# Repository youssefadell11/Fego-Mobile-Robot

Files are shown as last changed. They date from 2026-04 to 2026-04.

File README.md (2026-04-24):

# Fego Mobile Robot
This documentation provides a comprehensive overview of the design, assembly, and testing of the Fego mobile robot, a differential drive platform equipped with LiDAR and camera sensors. The project encompasses 3D CAD modeling, hardware integration, software visualization, and real-world performance demonstrations.

## 1. 3D CAD Design (Fusion 360)
The chassis and component placements were initially modeled in Autodesk Fusion 360 to ensure optimal weight distribution and sensor mounting.

<p align="center">
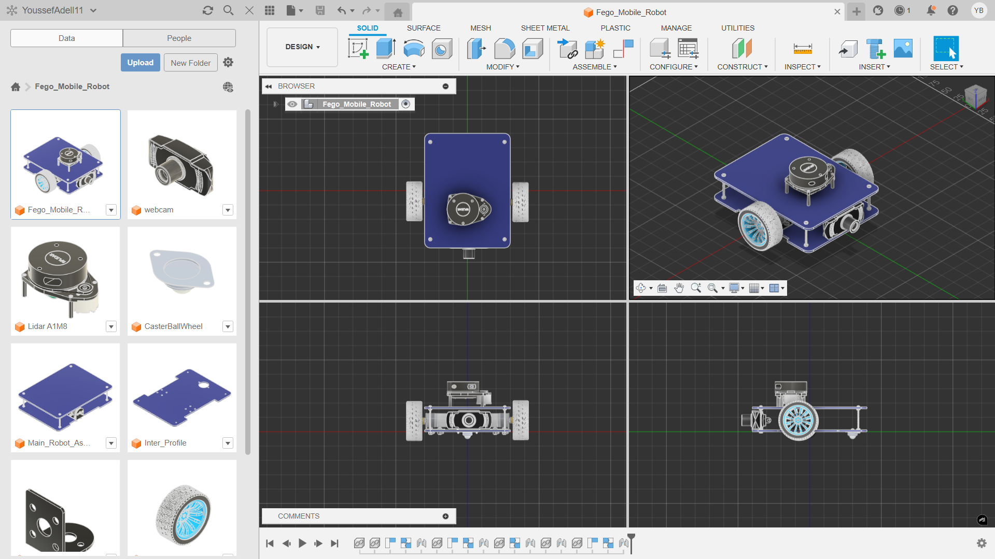
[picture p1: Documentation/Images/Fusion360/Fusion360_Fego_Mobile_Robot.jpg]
Fusion 360 Overall Model
  
</p>

<p align="center">
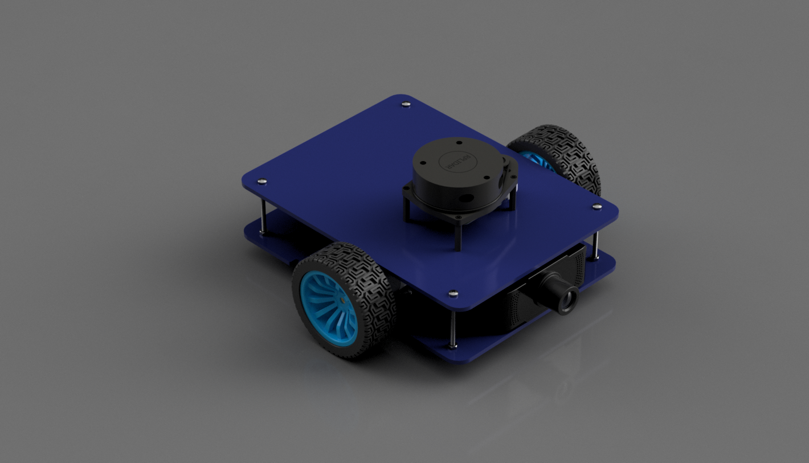
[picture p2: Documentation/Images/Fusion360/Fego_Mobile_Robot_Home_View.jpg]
Home View
  
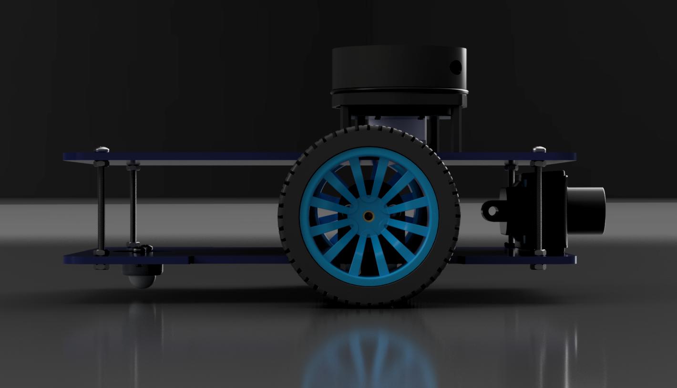
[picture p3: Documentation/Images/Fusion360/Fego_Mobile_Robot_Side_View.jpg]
Side View
  
</p>

---

## 2. Hardware Assembly & Real Robot
The physical build incorporates DC motors, an L298N motor driver, LiDAR, and a camera module. 

### Electronics & Wiring
<p align="center">
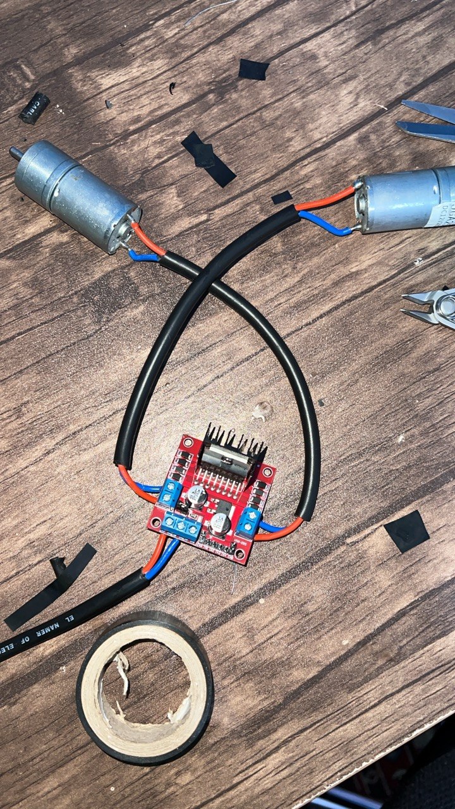
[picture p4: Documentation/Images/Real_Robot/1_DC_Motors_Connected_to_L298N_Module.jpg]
DC Motors Wiring
  
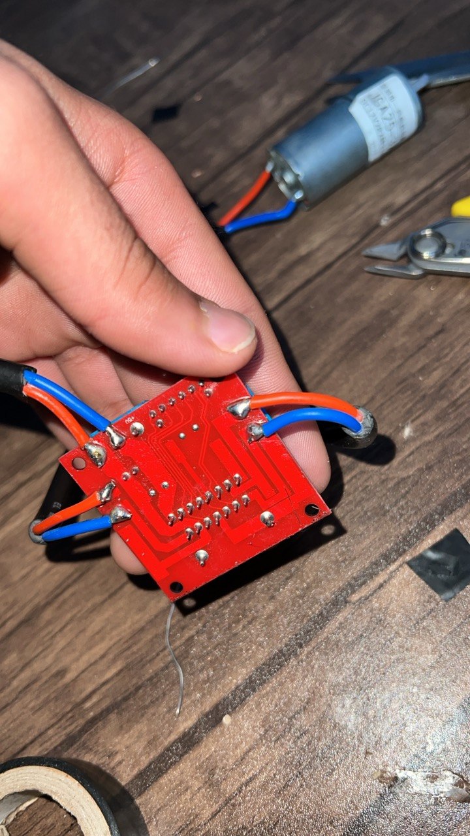
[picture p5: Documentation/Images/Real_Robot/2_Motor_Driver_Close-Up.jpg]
Motor Driver
  
</p>

### Chassis & Assembly Layout
<p align="center">
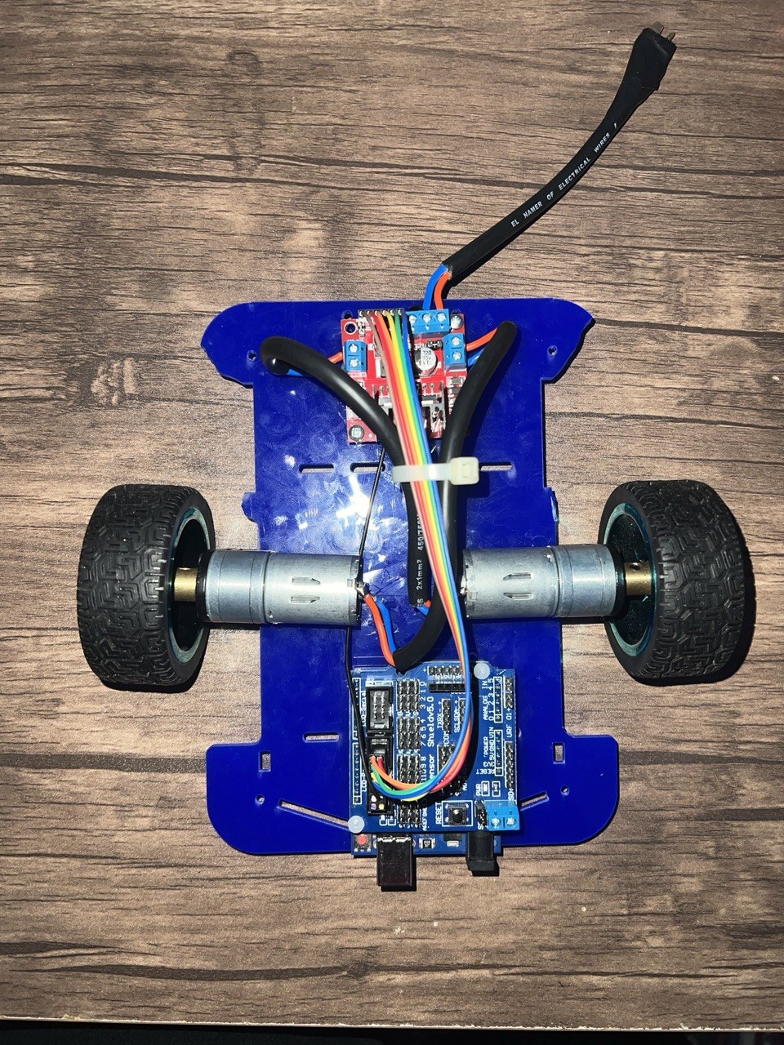
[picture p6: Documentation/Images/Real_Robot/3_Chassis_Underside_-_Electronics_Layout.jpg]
Underside Electronics
  
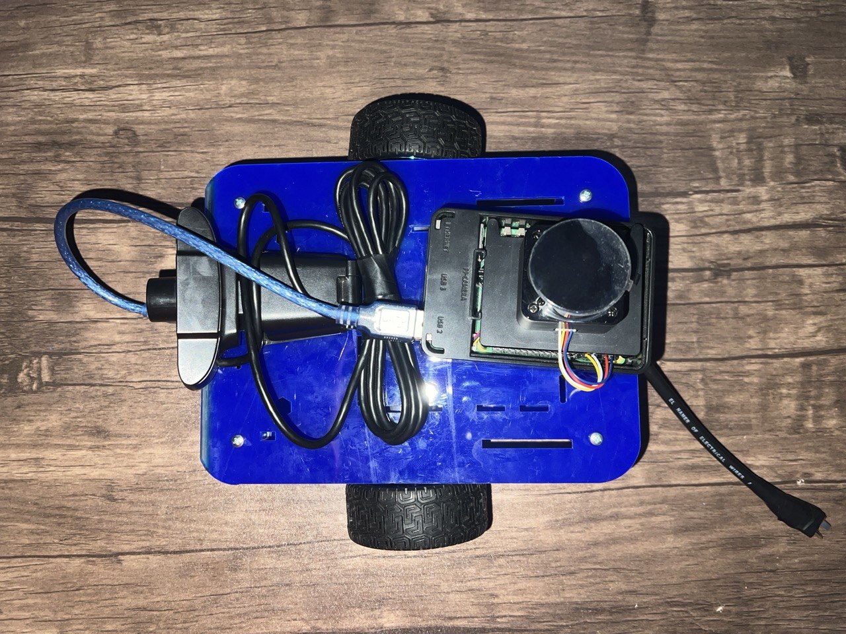
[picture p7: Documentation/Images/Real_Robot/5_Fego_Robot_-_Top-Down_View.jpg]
Top-Down View
  
</p>

### Final Assembled Platform
<p align="center">
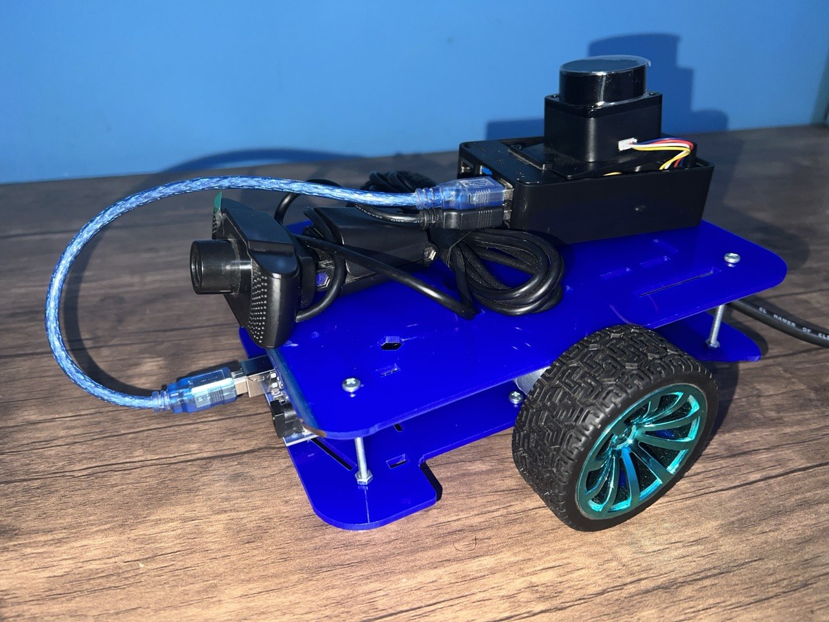
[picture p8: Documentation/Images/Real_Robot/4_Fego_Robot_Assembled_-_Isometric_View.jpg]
Fully Assembled Fego Robot
  
</p>

---

## 3. Software & Visualization
The robot's URDF, sensor data, and odometry are visualized in real-time using RViz.

<p align="center">
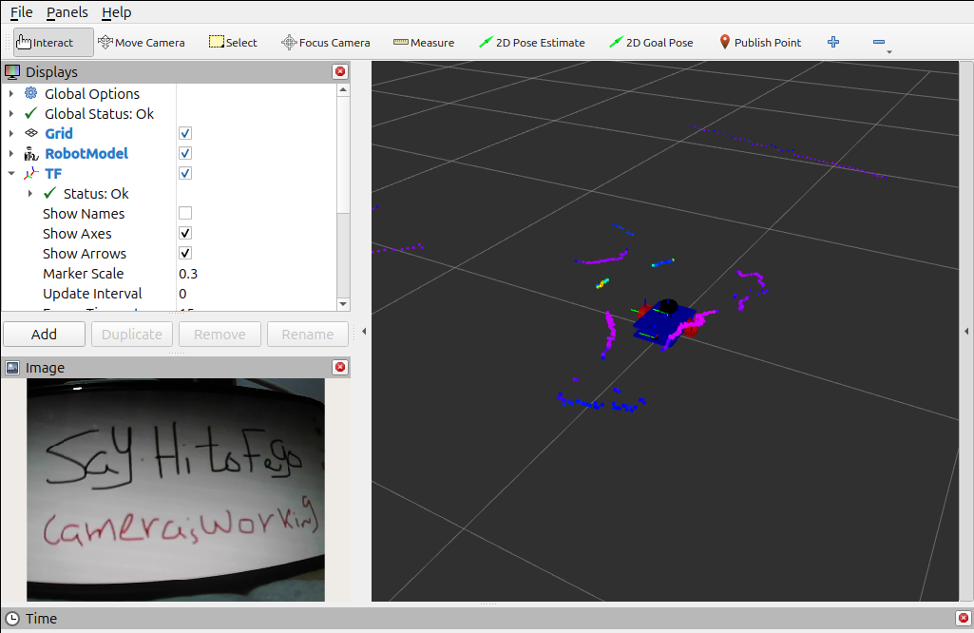
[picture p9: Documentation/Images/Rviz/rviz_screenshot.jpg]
RViz Visualization
  
</p>

---

## 4. Real-World Testing
Watch the Fego mobile base navigating and demonstrating its differential drive system and `ros2_control` integration.

<p align="center">
  <em>Please hit the image to see the YouTube video!</em><br>
</p>
<p align="center">
  <a href="https://youtu.be/x8awXbyMQPw">
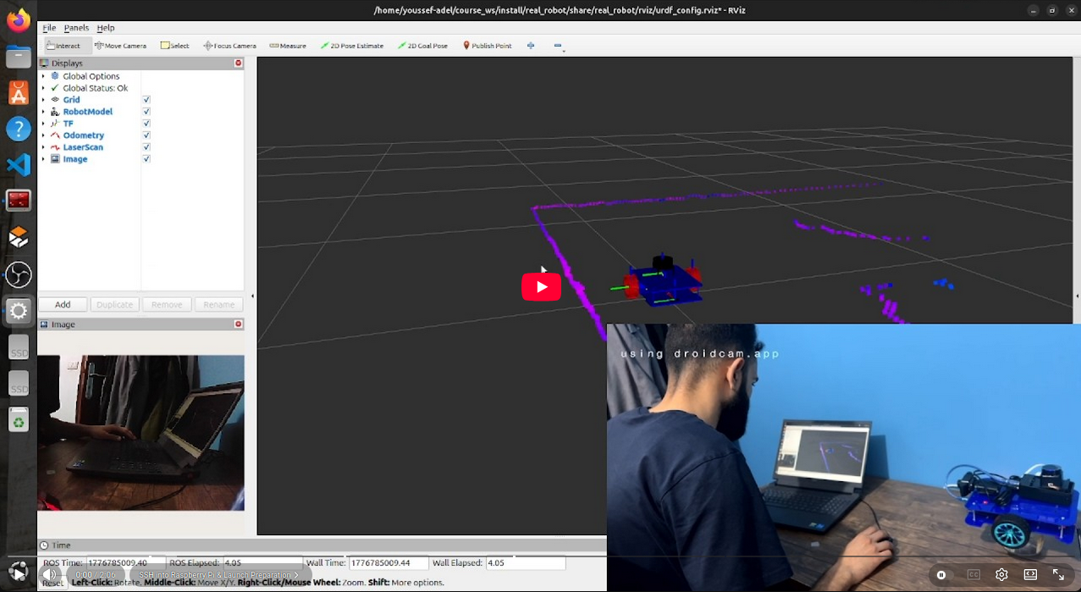
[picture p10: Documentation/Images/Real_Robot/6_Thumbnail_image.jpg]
Click to watch the Fego Robot video
    
  </a>
</p>

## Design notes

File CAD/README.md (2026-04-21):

# Fego Mobile Robot CAD

Welcome to the open-source CAD folder for the **Fego Mobile Robot**! This is a 2-Wheel Drive (2WD) differential mobile robot designed from the bottom-up using **`Fusion 360`**. 

This folder contains all the mechanical CAD files, manufacturing 2D profiles, and 3D meshes required to build the physical robot or simulate it in ROS 2 (RViz/Gazebo).
<p align="center">
Fusion360 Fego Mobile Robot
</p>

## 🗂️ Folder Structure

The CAD files in this folder are organized to help you find exactly what you need, whether you want to 3D print the whole robot, cut the chassis, or just borrow a sensor model for your own project.

### **`1_Full_Assembly/`**
Contains the complete, assembled robot model.
* `.step` - Universal 3D CAD file (Open in SolidWorks, Inventor, Onshape, etc.)
* `.f3d` - Native Fusion 360 archive with the complete design timeline and linked components.

### **`2_Components/`**
Individual `.step` files for standard third-party hardware and custom parts. You can easily drag and drop these into your own custom robot designs!
* Inter Profile
* Outer Profile
* Bracket 25mm
* RPLidar A1M8
* JGA25-370 TT Geared Motors
* 65mm Robot Wheels
* Caster Ball Wheel
* Webcam Module

### **`3_Manufacture_Files/`**
2D profiles and files for fabricating the custom parts.
* `.dxf` - Files for laser cutting or CNC routing the acrylic top and bottom plates.
* `.stl` - Files for 3D printing the 25mm Brackets.

### **`4_Meshes/`**
Optimized 3D meshes specifically exported for ROS 2 simulation (RViz/Gazebo).
* `lidar.stl`
* `base_link.stl`
* `camera.stl`
* `caster.stl`
* `wheel.stl`

### **`5_Renders/`**
High-quality, photorealistic images of the final assembly for reference and documentation.

---

## 🛠️ Main Components List

To build the electrical and sensor stack of this robot, the following major components are used:

* **Controller:** Arduino Mega (or Uno) & H-Bridge Motor Driver
* **Actuators:** 2x JGA25-370 TT Geared DC Motors with Encoders
* **Wheels:** 2x 65mm Rubber Tires with Plastic Rims, 1x Front Caster Ball Wheel
* **Vision / LiDAR:** RPLIDAR A1M8 & Forward-facing USB Webcam
* **Chassis:** 2x Custom Acrylic Plates (Top and Bottom)

---

## 🔩 Hardware & Fasteners Bill of Materials (BOM)

Below is the required hardware matrix for assembling the mechanical chassis and mounting the electronics.

| Subsystem / Assembly | Screws Required | Nuts Required | Spacers / Extras |
| :--- | :--- | :--- | :--- |
| **Main Chassis (Plates 1 & 2)** | 4x M3x50 | 12x M3 | - |
| **Motor Brackets** | 8x M4 | 8x M4 | - |
| **TT Motors** | 4x M3 | - | - |
| **Caster Wheel** | 2x M3 | 2x M3 | - |
| **Arduino & H-Bridge** | 8x M3 | 8x M3 | 8x M3 Spacers |

---

## 🚀 Getting Started

**To build the physical robot:**
1. Laser cut the top and bottom plates using the `.dxf` files in `3_Manufacture_Files/`.
2. 3D print the 25mm brackets.
3. Gather the components listed in the BOM.
4. Use the `1_Full_Assembly/` `.step` or `.f3d` file as a visual guide for putting it all together.

**To simulate in ROS 2:**
1. Copy the contents of `4_Meshes/` into the `meshes` folder of your ROS 2 description package.
2. Link them in your URDF/Xacro file. 

## 🇪🇬 Local Sourcing (Egyptian Market)
If you are building this robot in Egypt, you can easily source the main mechanical components from local electronics suppliers:

* **[Metal Caster Wheel](https://makerselectronics.com/product/metal-caster-wheel-for-robot/)** 
  * *Makers Electronics*
* **[Main Chassis / 2WD Platform](https://makerselectronics.com/product/robot-platform-2wd-square-shape/)** 
  * *Makers Electronics* (Note: This is a great alternative if you don't want to laser cut the custom acrylic plates).
* **[65mm Wheel & TT Motor Kit](https://electra.store/products/robot-wheel-65mm-with-gear-motor)** 
  * *Electra Store* (Includes the 65mm rubber wheels, TT gear motors, and the necessary motor mounting brackets).

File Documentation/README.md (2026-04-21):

# Fego Mobile Robot Documentation
This documentation provides a comprehensive overview of the design, assembly, and testing of the Fego mobile robot, a differential drive platform equipped with LiDAR and camera sensors. The project encompasses 3D CAD modeling, hardware integration, software visualization, and real-world performance demonstrations.

## 1. 3D CAD Design (Fusion 360)
The chassis and component placements were initially modeled in Autodesk Fusion 360 to ensure optimal weight distribution and sensor mounting.

<p align="center">
  Fusion 360 Overall Model
</p>

<p align="center">
  Home View
  Side View
</p>

---

## 2. Hardware Assembly & Real Robot
The physical build incorporates DC motors, an L298N motor driver, LiDAR, and a camera module. 

### Electronics & Wiring
<p align="center">
  DC Motors Wiring
  Motor Driver
</p>

### Chassis & Assembly Layout
<p align="center">
  Underside Electronics
  Top-Down View
</p>

### Final Assembled Platform
<p align="center">
  Fully Assembled Fego Robot
</p>

---

## 3. Software & Visualization
The robot's URDF, sensor data, and odometry are visualized in real-time using RViz.

<p align="center">
  RViz Visualization
</p>

---

## 4. Real-World Testing
Watch the Fego mobile base navigating and demonstrating its differential drive system and `ros2_control` integration.

<p align="center">
  <em>Please hit the image to see the YouTube video!</em><br>
</p>
<p align="center">
  <a href="https://youtu.be/x8awXbyMQPw">
    Click to watch the Fego Robot video
  </a>
</p>

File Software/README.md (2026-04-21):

# Fego Mobile Robot Software

A ROS 2 Jazzy differential-drive robot with Arduino-based motor control, LiDAR, and a USB camera. Three workspaces cover the full stack — from microcontroller firmware to remote visualization.





---

## 📁 Repository Structure

```
Fego/
├── firmware/       # Arduino sketch — low-level PWM motor driver
├── rpi_ws/         # Raspberry Pi workspace — core ROS 2 stack
├── laptop_ws/      # Laptop workspace — visualization & teleoperation
└── README.md       # This file
```
---

## 🖼️ System Visualization

### 💻 RViz2 Visualization

<p align="center">
Fusion360 Fego Mobile Robot
</p>
<p align="center">
Figure 1: Rviz2 showing the Fego Robot URDF, LaserScan data, and Camera feed.
</p>

### 🔄 Topic Network Overview
The system relies on a distributed node network. High-level commands flow from the Laptop to the Pi 5, while sensor data and hardware states flow back. 

<p align="center">
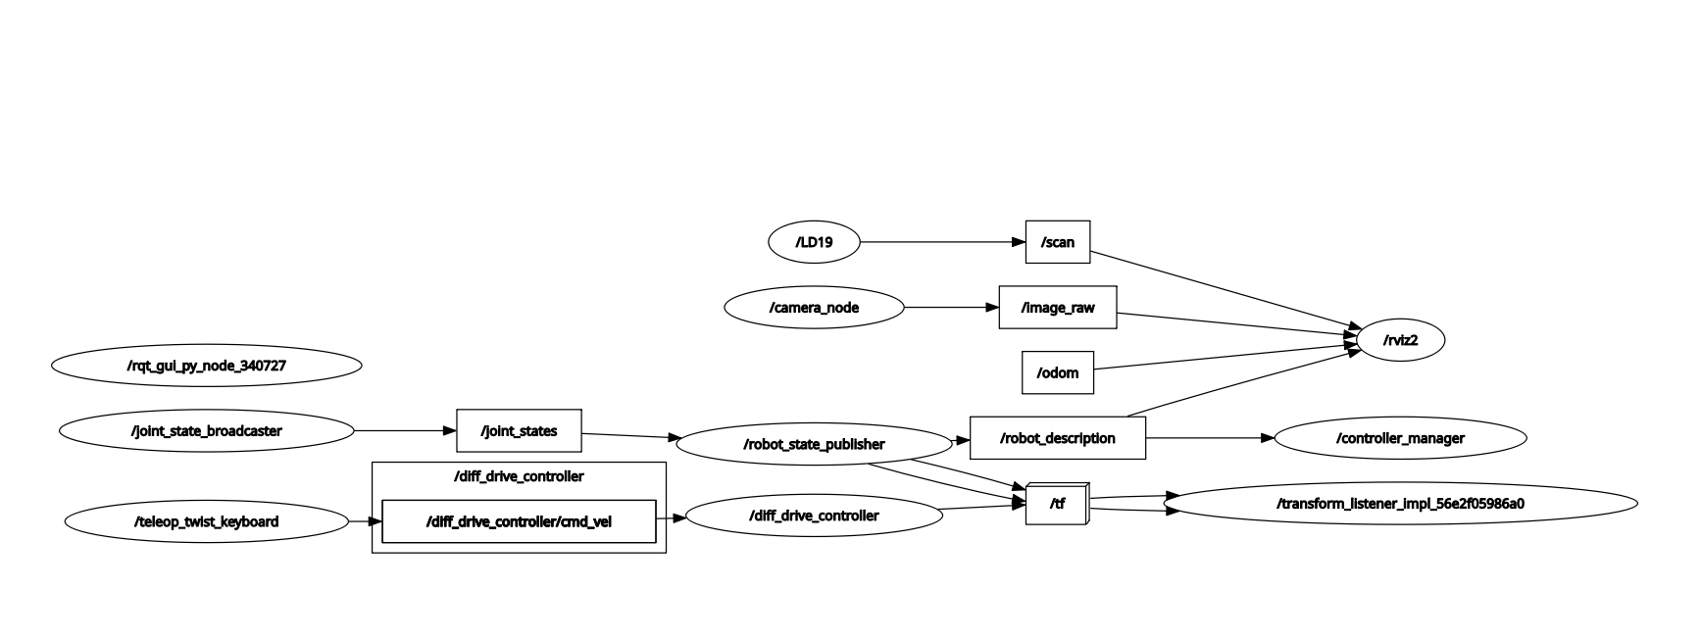
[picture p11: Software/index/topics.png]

</p>

* **Actuations:** `/cmd_vel` (Laptop → Pi 5) and `/cmd_vel_pwm` (Pi 5 → Arduino).
* **Sensors:** `/scan` (LiDAR) and `/image_raw` (Camera).
* **Transformations:** `/tf` and `/odom` for localization.

---

## 🏗️ System Architecture

```mermaid
flowchart TB
    Teleop["💻 Pc teleop_twist_keyboard"]
    CmdVel(["/cmd_vel"])
    DiffCtrl["🧠 Pi differential_drive_controller"]
    ros2(["ros2_control"])
    HW["🔀 Hardware Interface diffdrive_arduino"]
    Parser["⚙️ Serial Parser"]
    Watchdog["500ms Watchdog"]
    PWM["PWM Output"]
    Motors["🔩 Dual Motors"]

    Teleop --> CmdVel --> DiffCtrl --> ros2 --> HW
    HW -->|"USB Serial @ 115200"| Parser --> Watchdog --> PWM --> Motors

    LD19["🔴 LD19 LiDAR"]
    Lidar["ldlidar_stl_ros2"]
    Scan(["/scan"])
    RViz1["💻 RViz2 — scan"]

    LD19 --> Lidar --> Scan --> RViz1

    Webcam["📷 USB Webcam"]
    Cam["v4l2_camera"]
    Image(["/image_raw"])
    RViz2["💻 RViz2 — image"]

    Webcam --> Cam --> Image --> RViz2
```

> **Note:** Here is the [PDF for the system flowchart](/Software/index/Flowchart.pdf) if you want more information on how the hardware and ROS topics interact.
---

## 📦 Workspaces

### 📡 `firmware/` — Arduino Motor Driver
The `firmware.ino` sketch runs on the Arduino and acts as the direct hardware driver for the differential drive system. It listens for serial commands from the ROS 2 `diffdrive_arduino` hardware interface and outputs the corresponding PWM signals to the motor drivers.

- **Protocol:** `m <left_pwm> <right_pwm>\r` at 115200 baud
- **Safety:** 500ms watchdog — automatically halts motors if the Pi stops sending data

**Pin Configuration:**

| Side | Pin | Function |
| :--- | :---: | :--- |
| Left motor | 5 | PWM (speed) |
| | 6 | IN1 (direction) |
| | 7 | IN2 (direction) |
| Right motor | 10 | PWM (speed) |
| | 8 | IN3 (direction) |
| | 9 | IN4 (direction) |

**Upload:** Open `firmware.ino` in the Arduino IDE, select your board and port, then click **Upload**. Keep the Arduino connected via USB to the Raspberry Pi 5 before launching the ROS 2 stack.

---

### 🧠 `rpi_ws/` — Raspberry Pi Core Stack
The central nervous system of Fego. Manages the `ros2_control` lifecycle, communicates with the Arduino, and publishes sensor data (LiDAR and camera) to the ROS 2 network.

**Key packages:**
- `diffdrive_arduino` — Custom C++ `ros2_control` SystemInterface plugin that translates `rad/s` commands into PWM values and sends them over serial.
- `real_robot` — Robot URDF/Xacro description, `controllers.yaml`, and the master `fego.launch.xml` launch file.

**Hardware ports (defaults):**

| Device | Port | Baud |
| :--- | :--- | :--- |
| Arduino (motor driver) | `/dev/ttyUSB0` or `/dev/ttyACM0` | 115200 |
| LD19 LiDAR | `/dev/ttyAMA0` | 230400 |
| Webcam | USB (v4l2) | — |

> **Note:** The LD19 LiDAR requires the `ldlidar_stl_ros2` driver to be built in your workspace.

---

### 💻 `laptop_ws/` — Ground Control (PC)
Handles all graphical interfaces and remote monitoring. Contains no hardware drivers — the Raspberry Pi 5 handles all of that.

**Key files:**
- `src/real_robot/launch/display_real.launch.xml` — Primary PC launch file (boots RViz2, no hardware controllers).
- `src/real_robot/rviz/urdf_config.rviz` — Pre-configured RViz2 layout (robot model, LiDAR `/scan`, USB camera feed).
- `src/real_robot/meshes/` — Optimized 3D meshes: `base_link.stl`, `wheel.stl`, `caster.stl`, `lidar.stl`, `camera.stl`.

---

## 🛜 Network Configuration

Both the PC and Raspberry Pi must be on the **same Wi-Fi network** and share the **same `ROS_DOMAIN_ID`**.

Add this to your `.bashrc` on **both machines**:
```bash
export ROS_DOMAIN_ID=30
```

---

## 🚀 Quick Start

### Raspberry Pi

```bash
# 1. Install dependencies
sudo apt update
sudo apt install ros-jazzy-ros2-control ros-jazzy-ros2-controllers \
                 ros-jazzy-serial-driver ros-jazzy-v4l2-camera

# 2. Build the workspace
cd ~/rpi_ws
colcon build --packages-select diffdrive_arduino real_robot

# 3. Source the environment
source install/setup.bash

# 4. Launch the robot
ros2 launch real_robot fego.launch.xml
```

### Laptop (PC)

```bash
# 1. Add the drive alias (run once)
echo 'alias drive="ros2 run teleop_twist_keyboard teleop_twist_keyboard \
  --ros-args -p stamped:=true -p frame_id:=base_footprint \
  -r cmd_vel:=/diff_drive_controller/cmd_vel"' >> ~/.bashrc
source ~/.bashrc

# 2. Build the workspace
cd ~/laptop_ws
colcon build --packages-select real_robot
source install/setup.bash

# 3. Launch RViz2 visualization
ros2 launch real_robot display_real.launch.xml

# 4. Teleoperate (open a new terminal)
drive
```

---

## 🔍 Debugging & Verification

```bash
# List all active ROS 2 topics
ros2 topic list

# Monitor target velocity from keyboard
ros2 topic echo /cmd_vel

# Monitor actual PWM values sent to the Arduino
ros2 topic echo /cmd_vel_pwm
```

---

## 📋 Dependencies Summary

| Package | Where |
| :--- | :--- |
| `ros-jazzy-ros2-control` | Raspberry Pi |
| `ros-jazzy-ros2-controllers` | Raspberry Pi |
| `ros-jazzy-serial-driver` | Raspberry Pi |
| `ros-jazzy-v4l2-camera` | Raspberry Pi |
| `ldlidar_stl_ros2` | Raspberry Pi (build from source) |
| `teleop_twist_keyboard` | Laptop |

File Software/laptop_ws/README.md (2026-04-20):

# 💻 Fego Robot: Laptop Workspace (Ground Control)

This workspace is designed to run on the remote PC (host laptop). It handles all graphical interfaces, visualization, and remote monitoring for the Fego Robot, ensuring the Raspberry Pi 5 reserves its processing power for hardware control and autonomous navigation algorithms.

## 📌 Overview
The `laptop_ws` contains the packages necessary to visualize the robot's physical state, sensor data, and environment mapping in real-time using RViz2. 

## 📂 Directory Structure
- **`src/real_robot/launch/`**
  - `display_real.launch.xml`: The primary launch file for the PC. It connects to the ROS 2 network and boots up the visualization tools without attempting to spawn hardware controllers.
- **`src/real_robot/rviz/`**
  - `urdf_config.rviz`: A pre-configured RViz2 layout tailored for Fego. It includes displays for the robot model (URDF), the LD19 LiDAR `/scan` data, and the USB Camera feed.
- **`src/real_robot/meshes/`**
  - Optimized 3D meshes specifically exported for ROS 2 simulation (RViz).
    * `lidar.stl`
    * `base_link.stl`
    * `camera.stl`
    * `caster.stl`
    * `wheel.stl`

## 🛜 Network Configuration
For this workspace to communicate with the Fego Robot, both the PC and the Raspberry Pi must be on the same Wi-Fi network and share the same `ROS_DOMAIN_ID`.

Export the domain ID in your terminal (or add it to your `.bashrc`):
```bash
export ROS_DOMAIN_ID=30 # Ensure this matches the Pi!
```
## 🛠️ USEFUL COMMANDS & SETUP

### 1. Create the 'drive' alias in your .bashrc (Run this once on the Pc)

```bash
echo 'alias drive="ros2 run teleop_twist_keyboard teleop_twist_keyboard --ros-args -p stamped:=true -p frame_id:=base_footprint -r cmd_vel:=/diff_drive_controller/cmd_vel"' >> ~/.bashrc
source ~/.bashrc
```
### 2. Build the workspace and source it
```bash
cd ~/laptop_ws
colcon build --packages-select real_robot
source install/setup.bash
```

### 3. Launch the main robot stack
```bash
ros2 launch real_robot display_real.launch.xml
```
### 4. Teleoperate the robot (Open a new terminal)
Since we added the alias in step 1, you simply type:
```bash
drive
```
### 5. Debugging & Verification (Open a new terminal)
List all active topics:
```bash
ros2 topic list
```
See the target velocity from the keyboard:
```bash
ros2 topic echo /cmd_vel
```
See the actual PWM values being sent to the Arduino:
```bash
ros2 topic echo /cmd_vel_pwm
```

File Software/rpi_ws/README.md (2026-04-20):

# 🧠 Fego Robot: Raspberry Pi Workspace (Core)

This workspace runs on the Raspberry Pi 5. It is the central nervous system of the Fego Robot, responsible for managing the `ros2_control` lifecycle, communicating with the Arduino motor driver, and publishing sensor data (LiDAR and Camera) to the ROS 2 network.

## 📌 Overview
The `rpi_ws` utilizes ROS 2 Jazzy to bridge high-level navigation commands & Teleop commands (`cmd_vel`) down to physical hardware. It relies heavily on a custom-written hardware interface plugin that bypasses standard motor controllers to talk directly to a "Dumb Arduino" via serial communication.

## 📂 Directory Structure

### 1. `diffdrive_arduino` (Custom Hardware Interface)
A custom C++ `ros2_control` SystemInterface plugin.
- **`src/arduino_interface.cpp`**: Implements the `on_init`, `on_activate`, `read`, and `write` lifecycle nodes. It calculates the necessary PWM values based on incoming `rad/s` commands.
- **`include/diffdrive_arduino/arduino_comms.hpp`**: Handles the low-level, high-speed asynchronous serial communication (115200 baud) using the official ROS 2 `serial_driver`.

### 2. `real_robot` (Robot Configuration & Launch)
Contains the physical description and startup routines for Fego.
- **`urdf/`**: Modular Xacro/URDF files defining the robot's links, joints, and `ros2_control` hardware tags (`robot.urdf.xacro`, `ros2_control.xacro`, `lidar.xacro`, `camera.xacro`).
- **`meshes/`**: Optimized 3D meshes specifically exported for ROS 2 simulation (`RViz`).
    * `lidar.stl`
    * `base_link.stl`
    * `camera.stl`
    * `caster.stl`
    * `wheel.stl`
- **`config/`**: Contains `controllers.yaml` for setting up the `diff_drive_controller` and `joint_state_broadcaster`.
- **`launch/`**:
  - `fego.launch.xml`: The master launch file. Starts the `controller_manager`, spawns controllers, and boots up all sensor nodes (LiDAR & Camera).

## 🛠️ Hardware Requirements & Ports
Before launching, ensure the physical connections match your configuration files:
- **Arduino (Motor Driver):** Connected via USB (Defaults to `/dev/ttyUSB0` or `/dev/ttyACM0`).
- **LD19 LiDAR:** Connected via Serial/USB (Defaults to `/dev/ttyAMA0` at 230400 baud).
- **Webcam:** Connected via USB.
  
(Note: The LD19 LiDAR requires its specific SDK/ROS2 driver ldlidar_stl_ros2 to be built in your workspace).

## 🛜 Network Configuration
For this workspace to communicate with the Fego Robot, both the PC and the Raspberry Pi must be on the same Wi-Fi network and share the same `ROS_DOMAIN_ID`.

Export the domain ID in your terminal (or add it to your `.bashrc`):
```bash
export ROS_DOMAIN_ID=30 # Ensure this matches the Pc!
```
## 📦 Dependencies
Ensure the following ROS 2 Jazzy packages are installed on the Pi:
```bash
sudo apt update
sudo apt install ros-jazzy-ros2-control ros-jazzy-ros2-controllers ros-jazzy-serial-driver ros-jazzy-v4l2-camera
```

## 🚀 Build & Launch Instructions
### 1. Build the workspace:
```bash
cd ~/rpi_ws
colcon build --packages-select diffdrive_arduino real_robot
```
### 2. Source the environment:
```bash
source install/setup.bash
```
### 3. Launch the Robot:
```bash
ros2 launch real_robot fego.launch.xml
```

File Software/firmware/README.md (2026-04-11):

# 🔌 Fego Robot: Arduino Firmware

This directory contains the low-level microcontroller code responsible for translating high-level commands from the Raspberry Pi into physical motor movements.

## 📌 Overview
The `firmware.ino` script runs on the Arduino and acts as the direct hardware driver for the differential drive system. It listens for serial commands from the ROS 2 `diffdrive_arduino` hardware interface and outputs the corresponding PWM signals to the motor drivers.

## ⚙️ Communication Protocol
- **Baud Rate:** 115200
- **Format:** The Arduino expects a string in the format `m <left_pwm> <right_pwm>\r`.
  - Example: `m 120 120` drives both motors forward.
  - Example: `m -100 100` turns the robot in place.

## 🛡️ Safety Features
- **Watchdog Timeout:** The firmware includes a 500ms safety check. If the serial connection drops or the Raspberry Pi stops sending `cmd_vel` data, the Arduino will automatically halt all motor outputs to prevent the robot from driving out of control.

## 🔌 Pin Configuration
Ensure your wiring matches the defined pins in the sketch:

| Component | Arduino Pin | Function |
| :--- | :--- | :--- |
| **Left Motor** | 5 | PWM (Speed) |
| | 6 | IN1 (Direction) |
| | 7 | IN2 (Direction) |
| **Right Motor** | 10 | PWM (Speed) |
| | 8 | IN3 (Direction) |
| | 9 | IN4 (Direction) |

## 🚀 How to Upload
1. Open `firmware.ino` in the Arduino IDE.
2. Select your Arduino board and the corresponding port.
3. Click **Upload**.
4. Keep the Arduino connected via USB to the Raspberry Pi 5 before launching the main ROS 2 stack.

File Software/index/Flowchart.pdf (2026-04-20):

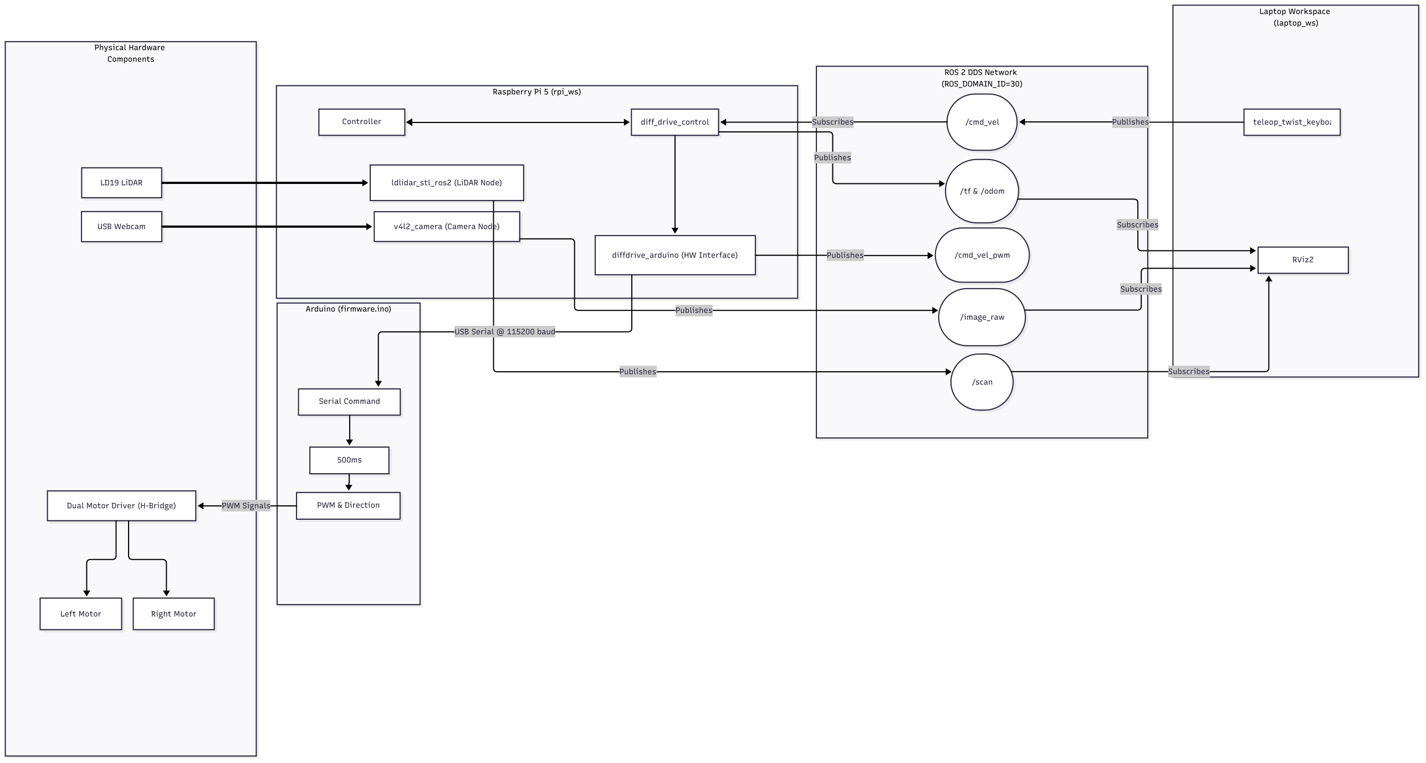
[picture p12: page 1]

Physical Hardware

Components

Arduino (firmware.ino)

Raspberry Pi 5 (rpi_ws)

ROS 2 DDS Network

(ROS_DOMAIN_ID=30)

Laptop Workspace

(laptop_ws)

RViz2

/cmd_vel | teleop_twist_keyboa

/scan

/image_raw

/tf & /odom

/cmd_vel_pwm

Controller | diff_drive_control

diffdrive_arduino (HW Interface) ldlidar_stl_ros2 (LiDAR Node)

v4l2_camera (Camera Node)

Serial Command

500ms

Dual Motor Driver (H-Bridge) | PWM & Direction

Right Motor

LD19 LiDAR

USB Webcam

Left Motor

Publishes

Subscribes

Subscribes

Subscribes

Subscribes

Publishes

Publishes

PWM Signals

Publishes

USB Serial @ 115200 baud

Publishes

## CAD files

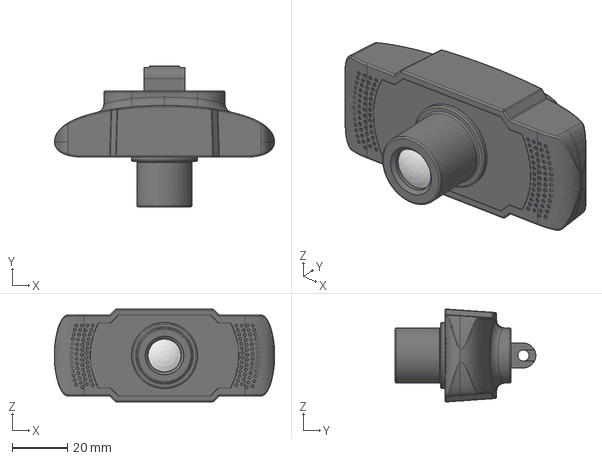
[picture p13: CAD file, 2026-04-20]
CAD/2_Components/Webcam.step
79.7 x 51.0 x 33.7 mm

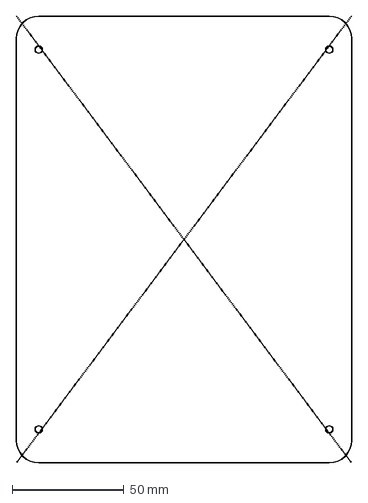
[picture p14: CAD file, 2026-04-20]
CAD/3_Manufacture_Files/Bottom_Plate.dxf
150.0 x 200.0 mm

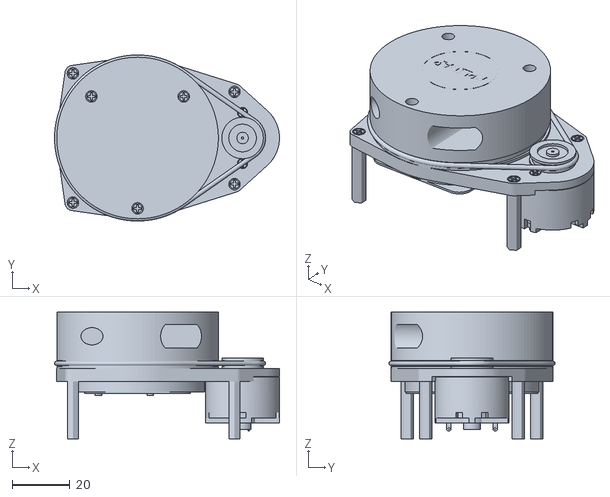
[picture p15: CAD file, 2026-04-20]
Software/rpi_ws/src/real_robot/meshes/lidar.stl
78.0 x 57.6 x 44.0

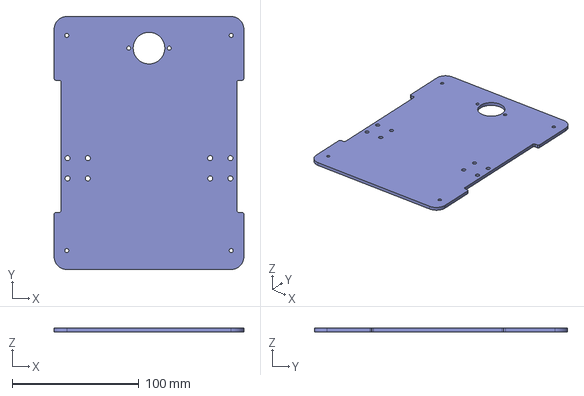
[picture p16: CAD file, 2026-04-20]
CAD/2_Components/Inter_Profile.step
150.0 x 200.0 x 3.00 mm

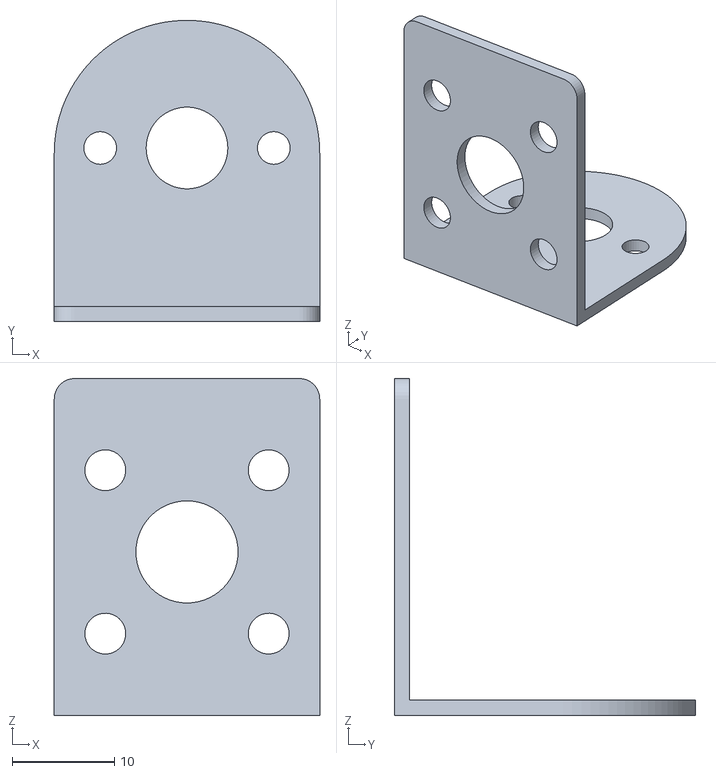
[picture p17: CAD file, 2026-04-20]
CAD/3_Manufacture_Files/Standoffs_3DPrint.stl
26.0 x 29.5 x 33.0

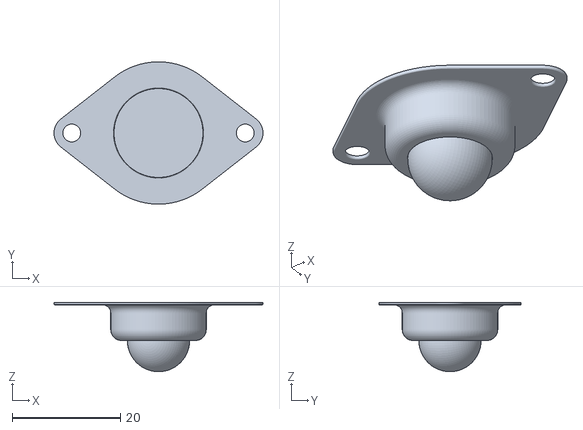
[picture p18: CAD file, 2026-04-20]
Software/rpi_ws/src/real_robot/meshes/caster.stl
38.5 x 26.2 x 12.8

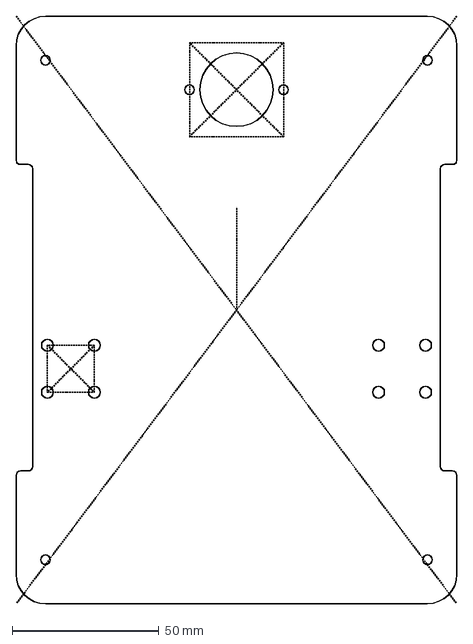
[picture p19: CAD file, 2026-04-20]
CAD/3_Manufacture_Files/Top_Plate.dxf
150.0 x 200.0 mm

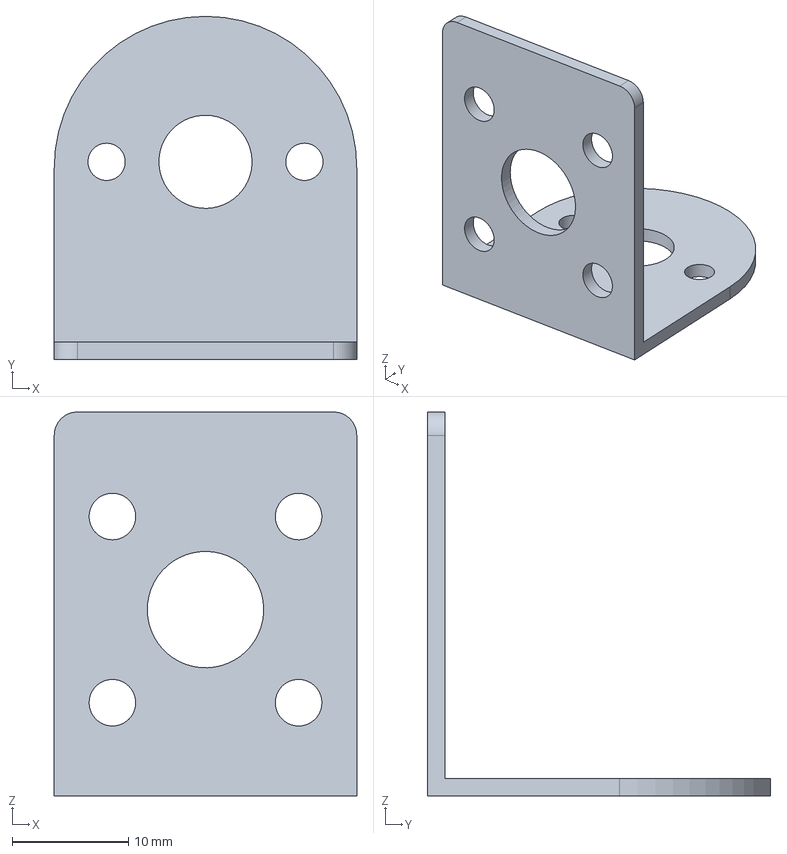
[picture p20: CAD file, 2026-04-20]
CAD/2_Components/Bracket25mm.step
26.0 x 29.5 x 33.0 mm

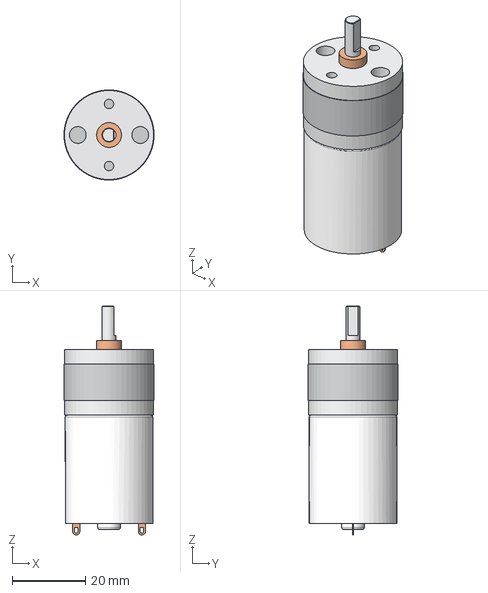
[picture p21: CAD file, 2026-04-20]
CAD/2_Components/GearedDCmotor.step
24.7 x 24.7 x 62.7 mm

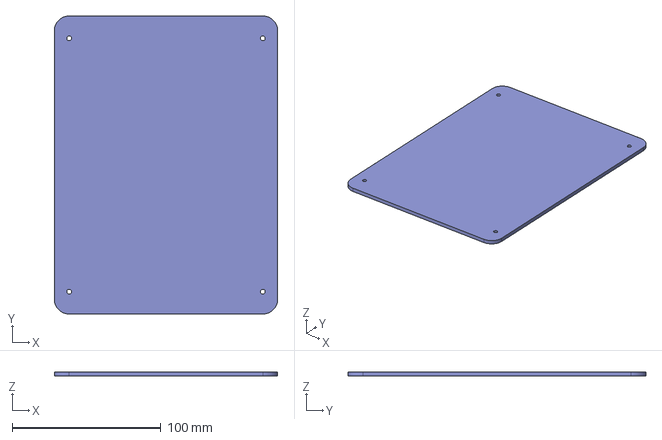
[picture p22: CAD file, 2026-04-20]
CAD/2_Components/Outer_Profile.step
150.0 x 200.0 x 3.00 mm

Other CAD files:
Software/laptop_ws/src/real_robot/meshes/camera.stl
CAD/2_Components/CasterBallWheel.step
Software/rpi_ws/src/real_robot/meshes/camera.stl
CAD/2_Components/RPLidar_A1M8.step

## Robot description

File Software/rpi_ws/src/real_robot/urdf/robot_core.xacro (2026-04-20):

<?xml version="1.0"?>
<robot xmlns:xacro="http://www.ros.org/wiki/xacro">

    <material name="blue">
        <color rgba="0 0 1 1"/> 
    </material>

    <material name="red">
        <color rgba="1 0 0 0.5"/> 
    </material>
    
    <material name="black">
        <color rgba="0 0 0 1"/>
    </material>

    <link name="base_footprint"/>

    <joint name="base_footprint_to_base_link_joint" type="fixed">
        <parent link="base_footprint"/> 
        <child link="base_link"/>
        <origin xyz="0 0 0.0125" rpy="0 0 0"/> 
    </joint>

    <link name="base_link">
        <visual>
            <geometry>
                <mesh filename="package://${pkg}/meshes/base_link.stl" scale="0.001 0.001 0.001"/>
            </geometry>
            <origin xyz="0 0 0" rpy="0 0 1.5708"/> 
            <material name="blue"/>
        </visual>
        <collision>
            <geometry>
                <box size="0.2 0.15 0.05"/>
            </geometry>
            <origin xyz="0 0 0.02" rpy="0 0 0"/> 
        </collision>
        <inertial>
            <origin xyz="0 0 0.02" rpy="0 0 0"/> 
            <mass value="2.0"/>
            <inertia ixx="0.004566" ixy="0.0" ixz="0.0" iyy="0.007483" iyz="0.0" izz="0.010416"/>
        </inertial>
    </link>

    <joint name="base_right_wheel_joint" type="continuous">
        <parent link="base_link"/> 
        <child link="right_wheel_link"/>
        <origin xyz="0.022 -0.093 0.02" rpy="0 0 0"/> 
        
        <axis xyz="0 1 0"/> 
        
        <limit effort="1000.0" velocity="100.0"/>
        <dynamics damping="0.1" friction="0.1"/>
    </joint> 

    <link name="right_wheel_link">
        <visual>
            <geometry>
                <mesh filename="package://${pkg}/meshes/wheel.stl" scale="0.001 0.001 0.001"/>
            </geometry>
            <origin xyz="0 0 0" rpy="0 0 -1.5708"/> 
            <material name="red"/>
        </visual>
        <collision>
            <geometry>
                <cylinder radius="0.0325" length="0.026"/>
            </geometry>
            <origin xyz="0 0 0" rpy="1.5708 0 0"/>
        </collision>
        <inertial>
            <origin xyz="0 0 0" rpy="1.5708 0 0"/> 
            <mass value="0.04"/>
            <inertia ixx="0.0000128" ixy="0.0" ixz="0.0" iyy="0.0000211" iyz="0.0" izz="0.0000128"/>
        </inertial>
    </link>

    <joint name="base_left_wheel_joint" type="continuous">
        <parent link="base_link"/> 
        <child link="left_wheel_link"/>
        <origin xyz="0.022 0.093 0.02" rpy="0 0 0"/> 
        
        <axis xyz="0 1 0"/> 
        
        <limit effort="1000.0" velocity="100.0"/>
        <dynamics damping="0.1" friction="0.1"/>
    </joint>

    <link name="left_wheel_link">
        <visual>        
            <geometry>
                <mesh filename="package://${pkg}/meshes/wheel.stl" scale="0.001 0.001 0.001"/>
            </geometry>
            <origin xyz="0 0 0" rpy="0 0 1.5708"/>  
            <material name="red"/>
        </visual>
        <collision>
            <geometry>
                <cylinder radius="0.0325" length="0.026"/>
            </geometry>
            <origin xyz="0 0 0" rpy="1.5708 0 0"/>
        </collision>
        <inertial>
            <origin xyz="0 0 0" rpy="1.5708 0 0"/> 
            <mass value="0.04"/>
            <inertia ixx="0.0000128" ixy="0.0" ixz="0.0" iyy="0.0000211" iyz="0.0" izz="0.0000128"/>
        </inertial>
    </link>

    <joint name="base_castor_wheel_joint" type="fixed">
        <parent link="base_link"/> 
        <child link="castor_wheel_link"/>
        <origin xyz="-0.075 0 0.0025" rpy="0 0 0"/>  
    </joint>

    <link name="castor_wheel_link">
        <visual>
            <geometry>
                <mesh filename="package://${pkg}/meshes/caster.stl" scale="0.001 0.001 0.001"/>
            </geometry>
            <origin xyz="0 0 0" rpy="0 0 1.5708"/>  
            <material name="black"/>
        </visual>
        <collision>
            <geometry>
                <sphere radius="0.015" />
            </geometry>
            <origin xyz="0 0 0" rpy="0 0 0"/>
        </collision>
        <inertial>
            <origin xyz="0 0 0" rpy="0 0 0"/>  
            <mass value="0.05"/>
            <inertia ixx="0.0000045" ixy="0.0" ixz="0.0" iyy="0.0000045" iyz="0.0" izz="0.0000045"/>
        </inertial>
    </link>

</robot>

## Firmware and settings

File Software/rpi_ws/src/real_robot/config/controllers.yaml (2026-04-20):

controller_manager:
  ros__parameters:
    update_rate: 30

    diff_drive_controller:
      type: diff_drive_controller/DiffDriveController

    joint_state_broadcaster:
      type: joint_state_broadcaster/JointStateBroadcaster

diff_drive_controller:
  ros__parameters:
    publish_rate: 50.0

    open_loop: true

    base_frame_id: base_footprint
    odom_frame_id: odom

    left_wheel_names: ["base_left_wheel_joint"]
    right_wheel_names: ["base_right_wheel_joint"]

    enable_odom_tf: true

    wheels_per_side: 1
    wheel_separation: 0.186
    wheel_radius: 0.0325

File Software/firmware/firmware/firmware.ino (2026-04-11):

// --- PIN CONFIGURATION ---
#define L_PWM 5   // Left Motor Speed
#define L_IN1 6   // Left Motor Direction 1
#define L_IN2 7   // Left Motor Direction 2
#define R_PWM 10  // Right Motor Speed
#define R_IN3 8   // Right Motor Direction 1
#define R_IN4 9   // Right Motor Direction 2

// --- SAFETY ---
unsigned long last_cmd_time = 0;
const unsigned long TIMEOUT_MS = 500; // Stop if no ROS 2 msg for 0.5s

void setup() {
  Serial.begin(115200); // MUST match URDF baud_rate
  
  pinMode(L_PWM, OUTPUT); pinMode(L_IN1, OUTPUT); pinMode(L_IN2, OUTPUT);
  pinMode(R_PWM, OUTPUT); pinMode(R_IN3, OUTPUT); pinMode(R_IN4, OUTPUT);
  
  stopMotors();
}

void loop() {
  if (Serial.available() > 0) {
    char start_char = Serial.read();
    
    // Check for our 'm' (motor) command
    if (start_char == 'm') {
      int left_pwm = Serial.parseInt();
      int right_pwm = Serial.parseInt();
      
      driveMotors(left_pwm, right_pwm);
      last_cmd_time = millis();
    }
  }

  // Safety Timeout
  if (millis() - last_cmd_time > TIMEOUT_MS) {
    stopMotors();
  }
}

void driveMotors(int l, int r) {
  // Left Motor
  if (l > 0) {
    digitalWrite(L_IN1, HIGH); digitalWrite(L_IN2, LOW);
  } else {
    digitalWrite(L_IN1, LOW); digitalWrite(L_IN2, HIGH);
  }
  analogWrite(L_PWM, abs(l));

  // Right Motor
  if (r > 0) {
    digitalWrite(R_IN3, HIGH); digitalWrite(R_IN4, LOW);
  } else {
    digitalWrite(R_IN3, LOW); digitalWrite(R_IN4, HIGH);
  }
  analogWrite(R_PWM, abs(r));
}

void stopMotors() {
  analogWrite(L_PWM, 0); analogWrite(R_PWM, 0);
}

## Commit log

2026-04-11 Initial structure for Fego Robot: Laptop workspace and documentation
    [camera.xacro, gazebo_control.xacro, inertial_macros.xacro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]
2026-04-20 CAD Folder
    [Bottom_Plate.dxf, Bracket25mm.step, CasterBallWheel.step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]
2026-04-20 CAD File
2026-04-20 Software File
    [camera.stl, camera.xacro, caster.stl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]
2026-04-24 Add initial README for Fego Mobile Robot project
    This documentation provides an overview of the Fego mobile robot, including design, assembly, and testing details.
